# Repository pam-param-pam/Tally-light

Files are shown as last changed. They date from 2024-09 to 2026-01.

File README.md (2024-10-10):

# Tally Light

Wireless tally light for use with ATEM switchers. 
It has 2 "modes of operation"

1) Connects to ATEM switcher via local wifi, requires tally to be in the same network as ATEM.

2) Connects to ATEM via "Relay Server" using websockets.
How does it work? Well Tally Light connects to Relay Server websocket which is accessible from the outer internet. Then theres a program in the same network as ATEM that listens for changes and sends data to Relay Server which then sends that data to Tally Light.

The tally Light has it's own setup page, which u can access by clicking the push button, connecting to tally's wifi, and typing `192.168.1.4` in the browser.

For the Tally Light, I used NODEMCU v3 esp8266 esp-12e. I added an external push button, Li-Pol rechargable battery and a charger. The cost was under 15$.

## Relay Server Protocol:
There are 2 endpoints on the Relay Server

| Endpoint  | Description |
| :--- | :--- |
| `/tally`  | For Tally Lights to connect to, and listen for upcoming events |
| `/atem` | For a program that monitors ATEM and sends info about the state of the SWITCHER |

Each event/message consists of a simple json. For example:
```
{"op": int, "t": int, "d": json/string}
```
't' represents an int from 0 to 64. Each Tally Light has it's ATEM source value assigned. When that value equals 't', 
it means that it's designated for the Tally Light. When 't' is 0, it means all Tally Lights have to act on it.
Different OP codes mean different events:

| op  | Event | Type | Data payload | Description |
|:----|:---|:---|:---|:---|
| `1` | IDENTIFY | Tally -> Relay | `{"rId": int}` | must include Room ID, must be sent within 5 seconds of connecting to relay |
| `2` | PING | Atem -> Relay -> Tally | `"Hello there"` | Tally must respond to PING event with PONG event to inform that it's still listening | 
| `2` | PONG | Tally -> Relay -> Atem | `"General Kenobi"` | Atem may send this to tally to check if its still listening |
| `4` | PROGRAM CHANGE | Atem -> Relay -> Tally | `{"pg": int, "pv": int}` | program/preview change. pg and pv are program and preview source, each representing an int from 1 to 64 |
| `5` | NEW TALLY CONNECTED | Relay -> Atem | `"New tally connected"` | Sent to atem when a new tally connects |
| `6` | CHANGE BRIGHTNESS | Atem -> Relay -> Tally | `{"b": int}` | Brightness is an int from 0 to 255, the higher the brighter |
| `7` | TALLY DISCONNECTED | Relay -> Atem | `""` | Sent to atem when tally disconnects |
| `8` | ATEM DISCONNECTED | Relay -> Tally | `""` | Sent to tally when atem disconnects |
| `9` | STATUS CHECK | ATEM -> Relay -> Tally | `""` | Atem sends this to obtain Tally Lights status info |
| `9` | STATUS CHECK RESPONSE | Tally -> Relay -> ATEM | `"{"bV": int, "n": string, b": int, "c": int, "s": string}"` | Sent by tally, bW is battery voltage, b is brightness, c is color, s wifi name, n is tally name |

When connecting to `/atem`, you must include `room-id` header with Room ID 
there can only be 1 client connected to `/atem` per Room ID.

### Parts used
 - [Nodemcu v2](https://botland.com.pl/moduly-wifi-esp8266/4450-modul-wifi-esp-12e-nodemcu-v2-4mb-5903351241328.html)
 - [Li-Pol battery](https://botland.com.pl/akumulatory-li-pol-1s-37v/15613-akumulator-li-pol-akyga-1000mah-1s-37v-zlacze-jst-bec-gniazdo-48x30x7mm-5904422324230.html)
 - [Li-Pol battery charger](https://botland.com.pl/moduly-ladowania-lipol-usb-micro-usb/16979-ladowarka-li-pol-tp4056-pojedyncza-cela-1s-37v-usb-typ-c-z-zabezpieczeniami--5904422326708.html)- [RGB Led](https://botland.com.pl/diody-led-rgb/1667-dioda-led-5mm-rgb-matowa-wsp-katoda-5-szt-5903351244152.html)
 - wires
 - few resistors 10/22/44 ohm for RGB Led
 - few switch buttons
### esp8266 code based on

- [@AronHetLam's Tally Light](https://github.com/AronHetLam/ATEM_tally_light_with_ESP8266)

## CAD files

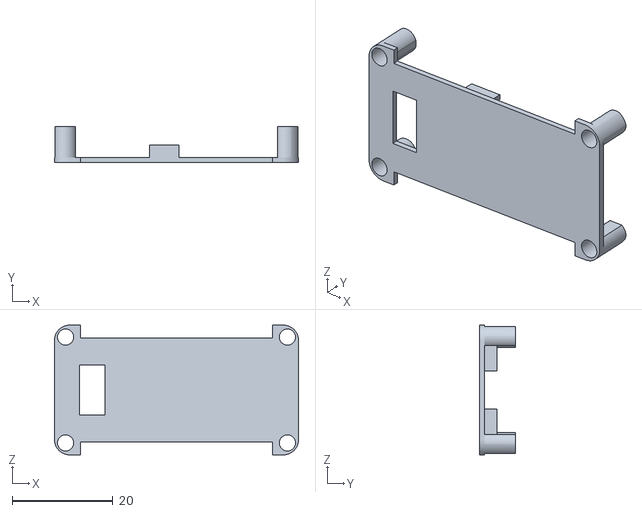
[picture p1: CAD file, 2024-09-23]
3D/floor.stl
48.4 x 7.20 x 25.8

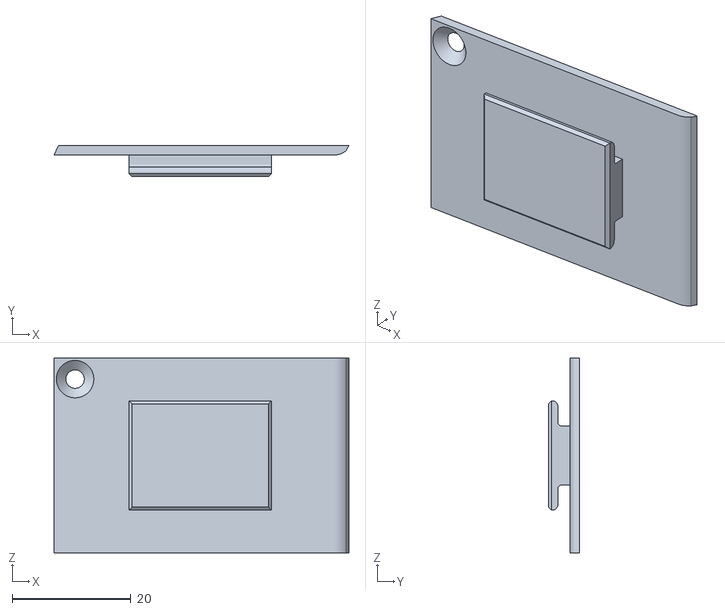
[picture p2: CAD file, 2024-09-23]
3D/door.stl
49.6 x 5.20 x 32.8

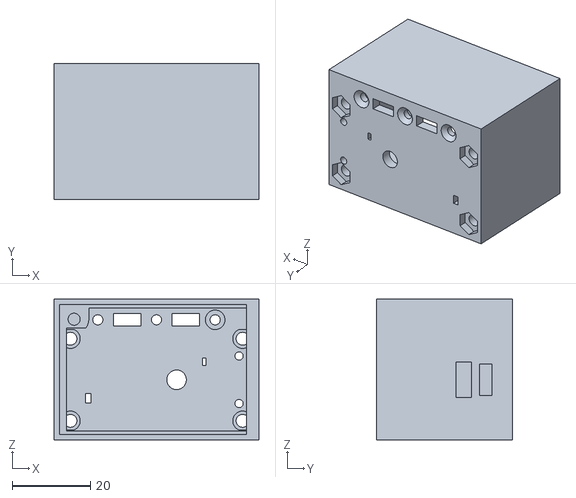
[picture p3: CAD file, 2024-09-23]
3D/case.stl
52.4 x 34.8 x 36.0

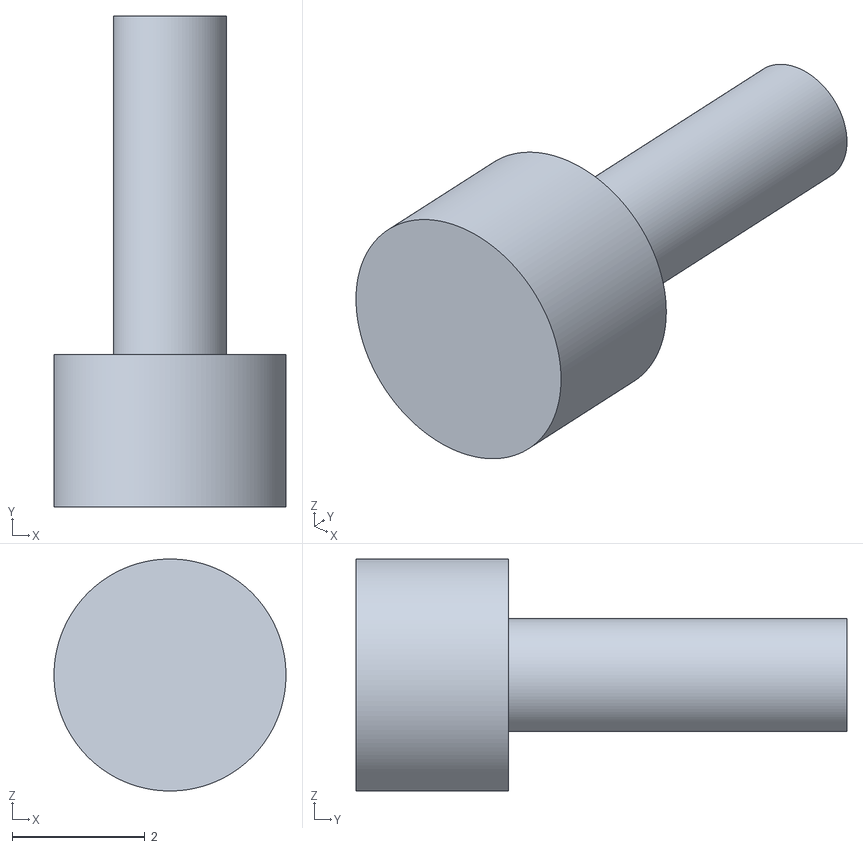
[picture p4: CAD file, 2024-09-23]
3D/button2.stl
3.50 x 7.40 x 3.50

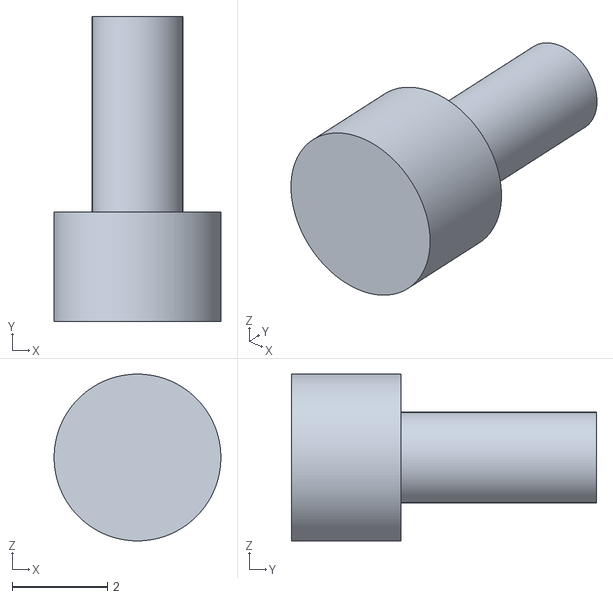
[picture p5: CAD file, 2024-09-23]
3D/button.stl
3.50 x 6.40 x 3.50

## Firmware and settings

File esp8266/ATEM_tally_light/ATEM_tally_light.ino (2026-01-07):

#include "ATEM_tally_light.hpp"

//Include libraries:
#include <Arduino.h>
#include <ArduinoJson.h>
#include <EEPROM.h>

#include <ESP8266WebServer.h>
#include <ESP8266WiFi.h>
#include <WebSocketsClient.h>

#include <Hash.h>
#include <ATEMmin.h>



#define DISPLAY_NAME "Tally Light"

//Define LED1 color pins
#ifndef PIN_RED1
#define PIN_RED1    0 // D3
#endif
#ifndef PIN_GREEN1
#define PIN_GREEN1  5  // D1
#endif
#ifndef PIN_BLUE1
#define PIN_BLUE1   13  // D7
#endif
#define LED_BUILTIN2 16

int BUTTON_PIN = 4;  //D6


//Define LED colors
#define LED_OFF     0
#define LED_RED     1
#define LED_GREEN   2
#define LED_BLUE    3
#define LED_YELLOW  4
#define LED_PINK    5
#define LED_WHITE   6
#define LED_ORANGE  7


//Define states
#define STATE_STARTING                  0
#define STATE_CONNECTING_TO_WIFI        1
#define STATE_CONNECTING_TO_SWITCHER    2
#define STATE_CONNECTING_TO_RELAY       3
#define STATE_SWITCHER_RUNNING          4
#define STATE_RELAY_RUNNING             5
#define SOFT_AP_ON                      6


//Define modes of operation
#define MODE_NORMAL                     1
#define MODE_PREVIEW_STAY_ON            2
#define MODE_PROGRAM_ONLY               3
#define MODE_ON_AIR                     4

#define TALLY_FLAG_OFF                  0
#define TALLY_FLAG_PROGRAM              1
#define TALLY_FLAG_PREVIEW              2


ESP8266WebServer server(80);

WebSocketsClient webSocket;

ATEMmin atemSwitcher;

uint8_t state = STATE_STARTING;

//Define struct for holding tally settings (mostly to simplify EEPROM read and write, in order to persist settings)
struct Settings {
    bool useRelayServer;
    char relayWsHost[64] = "";
    char relayWsPath[32] = "";
    char relayRoomID[16] = "";
    uint16_t relayWsPort;
    char tallyName[32] = "";
    uint8_t tallyNumber;
    bool staticIP;
    IPAddress tallyIP;
    IPAddress tallySubnetMask;
    IPAddress tallyGateway;
    IPAddress switcherIP;
    uint8_t ledBrightness;
};

Settings settings;

bool firstRun = true;
uint8_t currentLedColor;

//Vars for battery loop that monitors battery voltage
unsigned long batteryLoopStartTime = 0;
unsigned long batteryElapsedTime = 0;
unsigned long baterryStartTime = 0;
bool betteryLedState = false;
int rawBatteryRead;
double uBatt = 0;
char buffer[3];
unsigned int batteryLoopInterval = 500;

//Vars for button loop that monitors for push button change to enable/disable WIFI station mode for tally setup site
int buttonState = LOW;
int buttonReading;
int buttonPrevious = buttonState;




void webSocketEvent(WStype_t type, uint8_t * payload, size_t length) {
    switch(type) {
        case WStype_DISCONNECTED:
            Serial.printf("[WSc] Disconnected!\n");
            setLedColor(LED_PINK);
            break;
        case WStype_CONNECTED:  {
            Serial.printf("[WSc] Connected to url: %s\n",  payload);
            Serial.println("Sending identify EVENT");

            JsonDocument doc;
            doc["op"] = 1; // identify opcode
            doc["t"] = settings.tallyNumber + 1;
            doc["d"]["rId"] = settings.relayRoomID;
            String jsonString;
            serializeJson(doc, jsonString);
            webSocket.sendTXT(jsonString);
            break;
        }
        case WStype_PING:
            Serial.println("[WSc] got PING\n");
            break;

        case WStype_PONG:
            Serial.println("[WSc] got PONG");
            break;

        case WStype_TEXT: {
            Serial.printf("[WSc] got text: %s\n", payload);

            StaticJsonDocument<200> doc;
            DeserializationError error = deserializeJson(doc, payload, length);
            if (error) {
              Serial.println("Coulnd't parse json:");
              return;
            }
            uint8_t t_code = doc["t"];
            uint8_t op_code = doc["op"];

            if (op_code == 4) { // program/preview change
              setLedColor(LED_OFF);

              uint8_t preview = doc["d"]["pv"];
              if (preview == settings.tallyNumber + 1) {
                setLedColor(LED_GREEN);
                Serial.println("Set green");

              }

              uint8_t program = doc["d"]["pg"];
              if (program == settings.tallyNumber + 1) {
                setLedColor(LED_RED);
                Serial.println("Set red");

              }

            }
            else if (op_code == 2) { //PING, we need to respong with PONG(3)
              Serial.printf("[WSc] got PING EVENT");

              JsonDocument doc;
              doc["op"] = 2; // pong opcode(from tally)
              doc["t"] = settings.tallyNumber + 1;
              doc["d"] = "General Kenobi";
              String jsonString;
              serializeJson(doc, jsonString);
              webSocket.sendTXT(jsonString);

            } else if (op_code == 6) { //change brightness EVENT
              Serial.printf("[WSc] got change brightness EVENT");

              int brightness = doc["d"];
              settings.ledBrightness = brightness;
              EEPROM.put(0, settings);
              EEPROM.commit();
              setLedColor(currentLedColor);
            }
            else if (op_code == 8) { //atem disconnect event
              Serial.printf("[WSc] ATEM disconnected");

              setLedColor(LED_YELLOW);
            }
            else if (op_code == 9) { //status event
              Serial.printf("[WSc] status check");
              rawBatteryRead = analogRead(A0);
              uBatt = (double) rawBatteryRead / 1023 * 4.2;

              JsonDocument doc;
              doc["op"] = 9; // test connection opcode(from tally)
              doc["t"] = settings.tallyNumber + 1;
              doc["d"]["bV"] = uBatt;
              doc["d"]["b"] = settings.ledBrightness;
              doc["d"]["n"] = settings.tallyName;
              doc["d"]["c"] = currentLedColor;
              doc["d"]["s"] = WiFi.SSID();

              String jsonString;
              serializeJson(doc, jsonString);
              webSocket.sendTXT(jsonString);

            }

            break;
        }
    }

}
//Perform initial setup on power on
void setup() {

    //Start Serial
    Serial.begin(115200);
    Serial.println("########################");
    Serial.println("Serial started");
    Serial.setDebugOutput(true);

    //Init builtin led pins
    pinMode(LED_BUILTIN, OUTPUT);
    pinMode(LED_BUILTIN2, OUTPUT);

    // Initialize the button.
    pinMode(BUTTON_PIN, INPUT_PULLUP);

    //Init pins for LED
    pinMode(PIN_RED1, OUTPUT);
    pinMode(PIN_GREEN1, OUTPUT);
    pinMode(PIN_BLUE1, OUTPUT);

    //turn off two builtin leds
    digitalWrite(LED_BUILTIN, HIGH);
    digitalWrite(LED_BUILTIN2, HIGH);


    //Setup current-measuring pin
    pinMode(A0, INPUT);

    // //Read settings from EEPROM. WIFI settings are stored separately by the ESP
    EEPROM.begin(sizeof(settings)); //Needed on ESP8266 module, as EEPROM lib works a bit differently than on a regular Arduino
    EEPROM.get(0, settings);

    Serial.println(settings.tallyName);

    if (settings.staticIP && settings.tallyIP != IPADDR_NONE) {
        WiFi.config(settings.tallyIP, settings.tallyGateway, settings.tallySubnetMask);
    } else {
        settings.staticIP = false;
    }


    //Put WiFi into station mode and make it connect to saved network
    WiFi.mode(WIFI_STA);
    WiFi.hostname((String)settings.tallyName + " setup");
    WiFi.setAutoReconnect(true);
    WiFi.begin();

    Serial.println("------------------------");
    Serial.println("Connecting to WiFi...");
    Serial.println("Network name (SSID): " + getSSID());

    // Initialize and begin HTTP server for handeling the web interface
    server.on("/", handleRoot);
    server.on("/save", handleSave);
    server.onNotFound(handleNotFound);
    server.begin();

    //Set state to connecting before entering loop
    changeState(STATE_CONNECTING_TO_WIFI);

}

void loop() {
    switch (state) {
        case STATE_CONNECTING_TO_WIFI:
            if (WiFi.status() == WL_CONNECTED) {
                WiFi.mode(WIFI_STA); // Disable softAP if connection is successful
                Serial.println("------------------------");
                Serial.println("Connected to WiFi:   " + getSSID());
                Serial.println("IP:                  " + WiFi.localIP().toString());
                Serial.println("Subnet Mask:         " + WiFi.subnetMask().toString());
                Serial.println("Gateway IP:          " + WiFi.gatewayIP().toString());

                if (settings.useRelayServer) {
                  changeState(STATE_CONNECTING_TO_RELAY);
                } else {
                  changeState(STATE_CONNECTING_TO_SWITCHER);
                }
            } else if (firstRun) {
                firstRun = false;
                Serial.println("Unable to connect to WiFi");
            }
            break;

        case STATE_CONNECTING_TO_SWITCHER:
            // Initialize a connection to the switcher:
            if (firstRun && !atemSwitcher.isConnected()) {
                atemSwitcher.begin(settings.switcherIP);
                atemSwitcher.serialOutput(0xff); //Makes Atem library print debug info
                Serial.println("------------------------");
                Serial.println("Connecting to switcher...");
                Serial.println((String)"Switcher IP:         " + settings.switcherIP[0] + "." + settings.switcherIP[1] + "." + settings.switcherIP[2] + "." + settings.switcherIP[3]);
                firstRun = false;
            }
            atemSwitcher.runLoop();
            if (atemSwitcher.isConnected()) {
                changeState(STATE_SWITCHER_RUNNING);
                Serial.println("Connected to switcher");
            }
            break;

        case STATE_CONNECTING_TO_RELAY: {
          if (firstRun) {
            if (!webSocket.isConnected())
                Serial.println("Connecting to relay server...");
                Serial.println((String)"Switcher Host:         " + settings.relayWsHost);
                Serial.println((String)"Switcher Port:         " + settings.relayWsPort);
                Serial.println((String)"Switcher path:         " + settings.relayWsPath);

                //seting identify headers
                // String extraHeaders = String("tally-no: ") + String(settings.tallyNumber + 1) + "\r\n";
                // extraHeaders += String("room-id: ") + String(settings.relayRoomID);
                webSocket.beginSSL(settings.relayWsHost, settings.relayWsPort, settings.relayWsPath);
                // webSocket.setExtraHeaders(extraHeaders.c_str()); // Add the extra headers

                // webSocket.begin(settings.relayWsHost, settings.relayWsPort, settings.relayWsPath);
                webSocket.onEvent(webSocketEvent);
                firstRun = false;
          }
          webSocket.loop();
          if (webSocket.isConnected()) {
            Serial.println("--- connected ---");
            changeState(STATE_RELAY_RUNNING);
          }
          break;
        }

        case STATE_RELAY_RUNNING: {
            webSocket.loop();
            // if (webSocket.isConnected()) {
            //     webSocket.loop();
            // } else {
            //     changeState(STATE_CONNECTING_TO_RELAY);
            // }

            break;

        }

        case SOFT_AP_ON:
            server.handleClient();
            atemSwitcher.runLoop();
            break;

        case STATE_SWITCHER_RUNNING: {
            //Handle data exchange and connection to swithcher
            atemSwitcher.runLoop();

            int tallySources = atemSwitcher.getTallyByIndexSources();

            //Set LED color accordingly
            int color = getLedColor(settings.tallyNumber);
            setLedColor(color);

            //Switch state if ATEM connection is lost...
            if (!atemSwitcher.isConnected()) {
                Serial.println("------------------------");
                Serial.println("Connection to Switcher lost...");
                changeState(STATE_CONNECTING_TO_SWITCHER);

            }

            break;
        }
    }

    //Switch state if WiFi connection is lost...
    if (WiFi.status() != WL_CONNECTED && state != STATE_CONNECTING_TO_WIFI && state != SOFT_AP_ON) {
        Serial.println("------------------------");
        Serial.println("WiFi connection lost...");
        changeState(STATE_CONNECTING_TO_WIFI);
        if (!settings.useRelayServer) {
          //Force atem library to reset connection, in order for status to read correctly on website.
          atemSwitcher.begin(settings.switcherIP);
          atemSwitcher.connect();
        }
    }


    //monitor battery and button
    // Serial.println("=LOOP=");

    // batteryLoop();
    buttonLoop();

    // Serial.println("======FREE HEAP========");
    Serial.println(ESP.getFreeHeap());
    delay(100);
}

//Handle the change of states in the program
void changeState(uint8_t stateToChangeTo) {
    Serial.println("------------------------");
    Serial.println("state change...");
    firstRun = true;
    switch (stateToChangeTo) {
        case STATE_CONNECTING_TO_WIFI:
            state = STATE_CONNECTING_TO_WIFI;
            setLedColor(LED_BLUE);
            break;
        case STATE_CONNECTING_TO_SWITCHER:
            state = STATE_CONNECTING_TO_SWITCHER;
            setLedColor(LED_PINK);
            break;
        case STATE_CONNECTING_TO_RELAY:
            state = STATE_CONNECTING_TO_RELAY;
            setLedColor(LED_PINK);
            break;
        case STATE_SWITCHER_RUNNING:
            state = STATE_SWITCHER_RUNNING;
            setLedColor(LED_YELLOW);
            break;
        case STATE_RELAY_RUNNING:
            state = STATE_RELAY_RUNNING;
            setLedColor(LED_YELLOW);
            break;
        case SOFT_AP_ON:
            state = SOFT_AP_ON;
            setLedColor(LED_WHITE);
            firstRun = false;
            break;

    }
}

void setLedColor(uint8_t color) {
    currentLedColor = color;
    setLED(color, PIN_RED1, PIN_GREEN1, PIN_BLUE1);
}


// //Set the color of a LED using the given pins
void setLED(uint8_t color, int pinRed, int pinGreen, int pinBlue) {
    uint8_t ledBrightness = settings.ledBrightness;
    void (*writeFunc)(uint8_t, uint8_t);
    if(ledBrightness >= 0xff) {
        writeFunc = &digitalWrite;
        ledBrightness = 1;
    } else {
        writeFunc = &analogWriteWrapper;
    }

    switch (color) {
        case LED_OFF:
            Serial.println("LED OFF");
            digitalWrite(pinRed, 0);
            digitalWrite(pinGreen, 0);
            digitalWrite(pinBlue, 0);
            break;
        case LED_RED:
            writeFunc(pinRed, ledBrightness);
            digitalWrite(pinGreen, 0);
            digitalWrite(pinBlue, 0);
            break;
        case LED_GREEN:
            digitalWrite(pinRed, 0);
            writeFunc(pinGreen, ledBrightness);
            digitalWrite(pinBlue, 0);
            break;
        case LED_BLUE:
            digitalWrite(pinRed, 0);
            digitalWrite(pinGreen, 0);
            writeFunc(pinBlue, ledBrightness);
            break;
        case LED_YELLOW:
            writeFunc(pinRed, ledBrightness);
            writeFunc(pinGreen, ledBrightness);
            digitalWrite(pinBlue, 0);
            break;
        case LED_PINK:
            writeFunc(pinRed, ledBrightness);
            digitalWrite(pinGreen, 0);
            writeFunc(pinBlue, ledBrightness);
            break;
        case LED_WHITE:
            writeFunc(pinRed, ledBrightness);
            writeFunc(pinGreen, ledBrightness);
            writeFunc(pinBlue, ledBrightness);
            break;
    }

}

void analogWriteWrapper(uint8_t pin, uint8_t value) {
    analogWrite(pin, value);
}


int getTallyState(uint16_t tallyNo) {

    if(tallyNo >= atemSwitcher.getTallyByIndexSources()) { //out of range
        return TALLY_FLAG_OFF;
    }

    uint8_t tallyFlag = atemSwitcher.getTallyByIndexTallyFlags(tallyNo);

    if (tallyFlag & TALLY_FLAG_PROGRAM) {
        return TALLY_FLAG_PROGRAM;
    } else if (tallyFlag & TALLY_FLAG_PREVIEW) {
        return TALLY_FLAG_PREVIEW;
    } else {
        return TALLY_FLAG_OFF;
    }
}


int getLedColor(int tallyNo) {

    int tallyState = getTallyState(tallyNo);

    if (tallyState == TALLY_FLAG_PROGRAM) {   //if tally live
        return LED_RED;
    }
    else if (tallyState == TALLY_FLAG_PREVIEW) { //if tally preview
        return LED_GREEN;
    } else {
        return LED_OFF;   //if tally is neither
    }
}
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
